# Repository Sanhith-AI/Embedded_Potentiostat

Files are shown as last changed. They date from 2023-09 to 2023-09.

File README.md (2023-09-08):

# Embedded_Potentiostat
This project mainly focuses on the development and testing of an embedded potentiostat system that can perform electrochemistry methods like Cyclic voltammetry, Square wave voltammetry, Differential pulse voltammetry, and Impedance spectroscopy.
This project includes the circuit design and PCB design of a potentiostat and power supply using Eagle Autodesk software.
The software implementation includes driver development for SPI, UART, TIMERS, DACs, and ADCs of the STM32F303ZETx microcontroller using STM32cubeIDE as well as Eclipse IDE. Along with driver development, electrochemical methods and digital signal processing methods were implemented using a microcontroller and Matlab.
Moreover, a graphic user interface (GUI) was implemented using C# and Visual Studio to automate the measurement process of the developed potentiostat.

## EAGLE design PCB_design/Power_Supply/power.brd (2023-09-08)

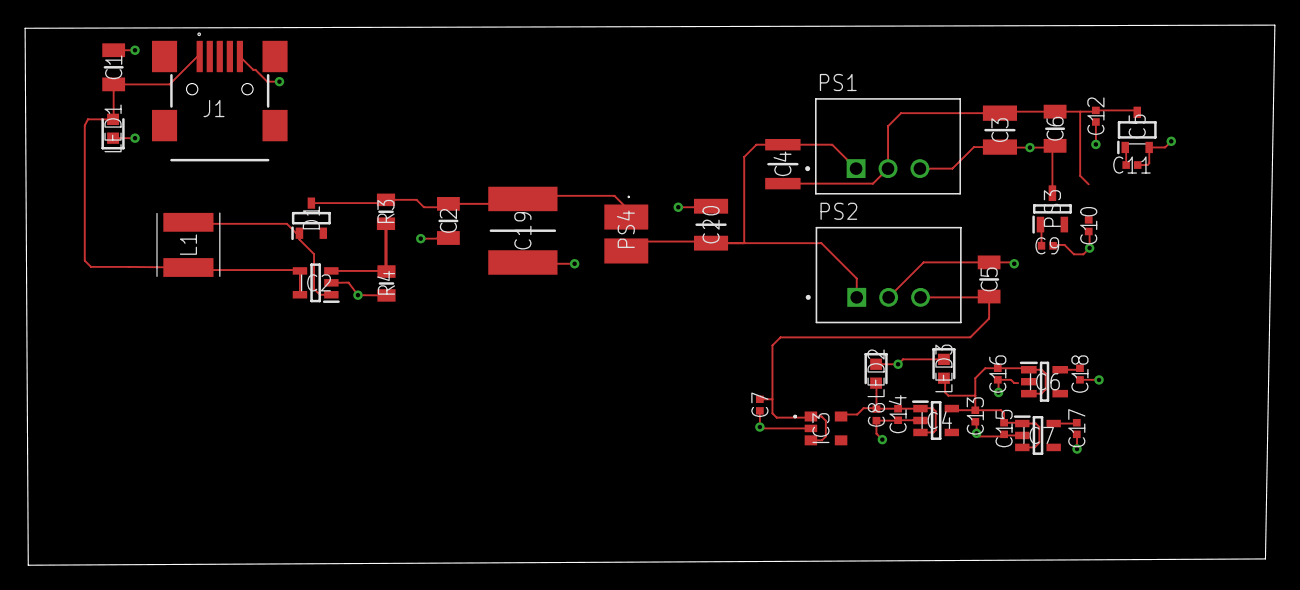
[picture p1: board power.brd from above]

Board: 2 copper layers, 99.5 x 43.0 mm, 38 parts (0 on the bottom side), 14 nets.

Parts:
C1, C2, C5, C6: LMF316AB7475KLHT; CAPC3216X180N
C3: LMF325B7106KMHP; CAPC3225X270N
C4: GRJ32ER71H106KE11L; CAPC3225X280N
C7, C8, C9, C10, C11, C12, C13, C14, C15, C16, C17, C18: GRM155R70J105KA12D; CAPC1005X55N
C19: KRM55QR72A106KH01L; CAPC6153X390N
C20: 12101C335KAT2A; CAPC3325X279N
D1: BAT54CHYFHT116; SOT95P240X115-3N
IC2: LM2703MFX-ADJ_NOPB; SOT95P280X145-5N
IC3: TCR2EF50,LM_CT; TCR2EF50LMCT
IC4: ADM7160AUJZ-2.5-R7; SOT95P280X100-5N
IC5: XC6902N251MR-G; SOT95P280X130-3N
IC6: NCV8114ASN165T1G; SOT95P275X110-5N
IC7: NCP163ASN150T1G; SOT95P280X145-5N
J1: 65100516121
L1: VLS5045EX-100M-H; VLS5045EX330M
LED1, LED2: LT_Q39G-Q1OO-25-1; LEDC1608X40N
LED3: LB_Q39E-N1OO-35-1; LEDC1608X40N
PS1, PS2: R-786.5-0.5; CONV_R-786.5-0.5
PS3: TC595002ECBTR; SOT95P275X130-3N
PS4: RLS-397; RLS397
R3, R4: TNPW080527K4BEEN; RESC2012X55N

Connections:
1.5V: C17.1, IC7.5
1.65V: C18.1, IC6.5
2.5V: C13.1, C15.1, C16.1, IC4.5, IC6.1, IC6.3, IC7.1, IC7.3, LED3.2
5V: C8.1, C14.1, IC3.5, IC4.1, IC4.3, LED2.2
6.5V: C5.1, C7.1, IC3.1, IC3.3, PS2.3
-2.5V: C11.1, IC5.1
-5V: C9.2, PS3.1
-6.5V: C3.2, C4.2, C6.1, C10.2, C12.1, IC5.3, PS1.2, PS3.2
GND: C1.2, C2.2, C3.1, C5.2, C6.2, C7.2, C8.2, C9.1, C10.1, C11.2, C12.2, C13.2, C14.2, C15.2, C16.2, C17.2, C18.2, C19.2, C20.2, IC2.2, IC3.2, IC4.2, IC5.2, IC7.2, J1.5, LED1.1, LED2.1, LED3.1, PS1.3, PS2.2, PS3.3, R4.2
IN: C2.1, C19.1, D1.3, PS4.1, R3.2
unnamed: IC2.3, R3.1, R4.1
unnamed: C4.1, C20.1, PS1.1, PS2.1, PS4.2
unnamed: D1.1, IC2.1, L1.2
VIN: C1.1, IC2.4, IC2.5, J1.1, L1.1, LED1.2

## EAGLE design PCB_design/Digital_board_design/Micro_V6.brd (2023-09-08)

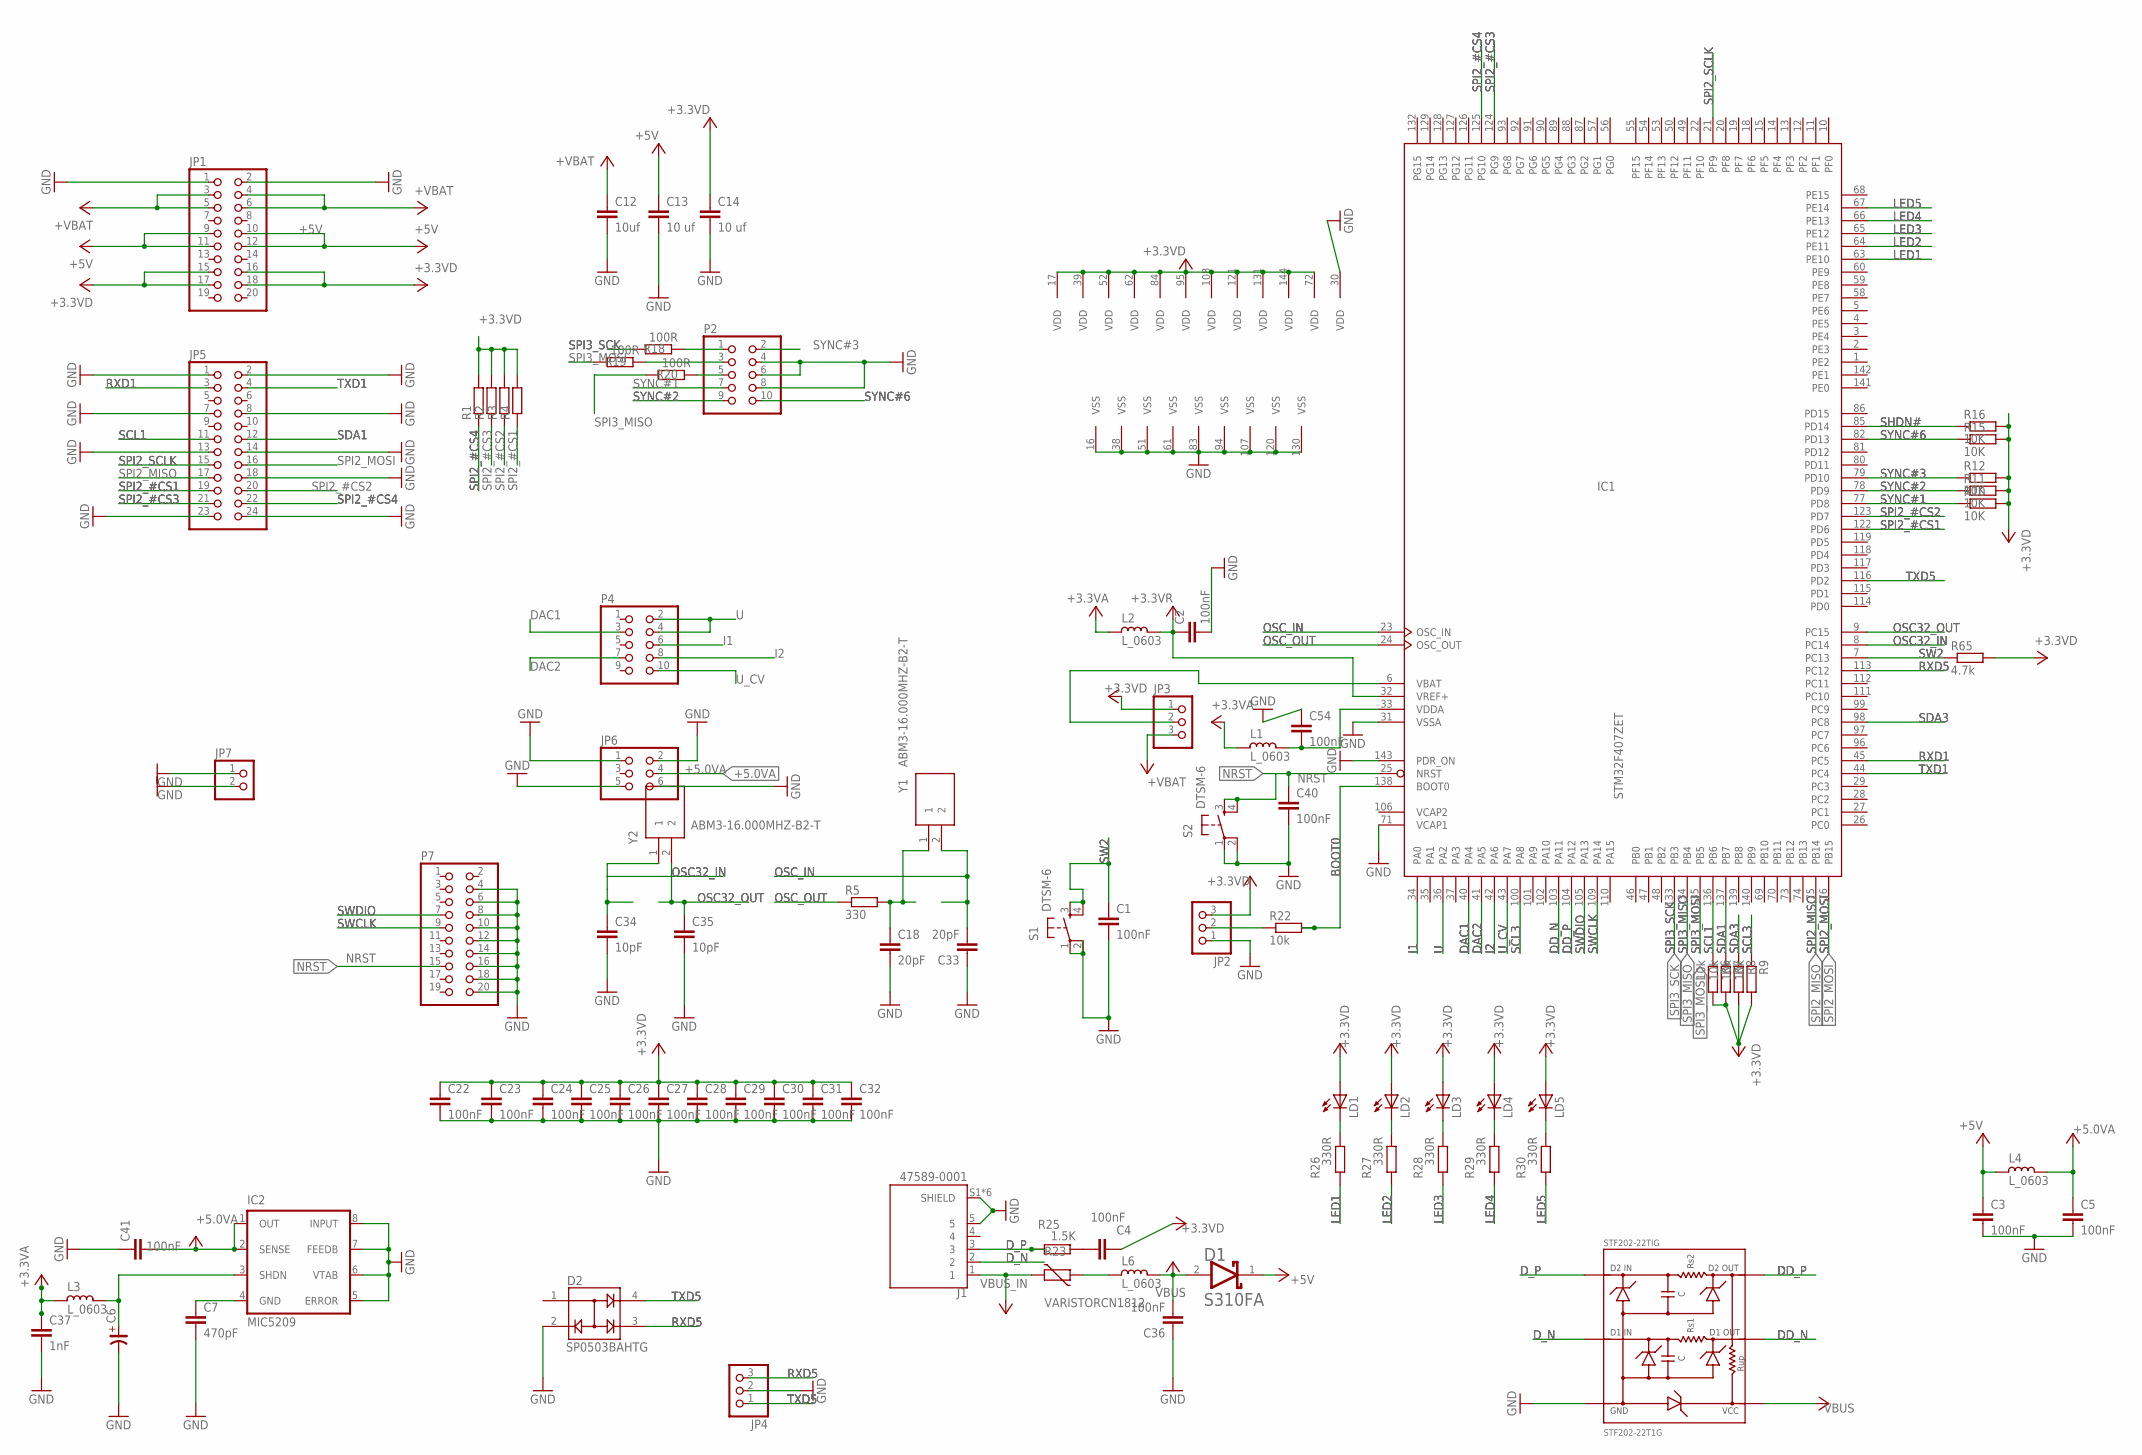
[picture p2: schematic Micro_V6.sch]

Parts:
C1, C2, C3, C4, C5, C22, C23, C24, C25, C26, C27, C28, C29, C30, C31, C32, C36, C40, C41, C54: 100nF; C0805
C6: CP_SV-A; CSV-A
C7: 470pF; C0805
C12: 10uf; C0805K
C13, C14: 10 uf; C0805K
C18, C33: 20pF; C0805
C34, C35: 10pF; C0805
C37: 1nF; C0805
D1: ON_SEMICONDUCTOR_S310FAON_SEMICONDUCTOR_S310FA_0_0; ON_SEMICONDUCTOR_S310FA_0
D2: SP0503BAHTG; SOT143
IC1: STM32F407ZET; LQFP144
IC2: MIC5209; SO-08
J1: 47589-0001; MOLEX_47589-0001
JP1: PINHD-2X10; 2X10
JP2, JP3, JP4: PINHD-1X3; 1X03
JP5: PINHD-2X12; 2X12
JP6: PINHD-2X3; 2X03
JP7: PINHD-1X2; 1X02
L1, L2, L3, L4, L6: L_0603; L0603
LD1, LD2, LD3, LD4, LD5: LEDSMT1206; 1206
P2, P4: PINHD-2X5; 2X05
P7: PINHD-2X10; 2X10
R1, R2, R3, R4: R-EU_R0603; R0603
R5: 330; R0603
R6, R7, R8, R9, R22: 10k; R0603
R10, R11, R12, R15, R16: 10K; R0603
R18, R19, R20: 100R; R0603
R23: VARISTORCN1812; CT/CN1812
R25: 1.5K; R0603
R26, R27, R28, R29, R30: 330R; R0603
R65: 4.7k; R0603
S1, S2: DTSM-6
STF202-22TIG: STF202-22T1G
Y1, Y2: ABM3-16.000MHZ-B2-T; ABM316000MHZB2T

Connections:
+3.3VA: C37.1, L1.2, L2.2, L3.2
+3.3VD: C4.1, C14.1, C22.1, C23.1, C24.1, C25.1, C26.1, C27.1, C28.1, C29.1, C30.1, C31.1, C32.1, IC1.17 (VDD), IC1.39 (VDD), IC1.52 (VDD), IC1.62 (VDD), IC1.72 (VDD), IC1.84 (VDD), IC1.95 (VDD), IC1.108 (VDD), IC1.121 (VDD), IC1.131 (VDD), IC1.144 (VDD), JP1.15, JP1.16, JP1.17, JP1.18, JP2.3, JP3.1, LD1.A, LD2.A, LD3.A, LD4.A, LD5.A, R1.2, R2.2, R3.2, R4.2, R6.2, R7.2, R8.2, R9.2, R10.2, R11.2, R12.2, R15.2, R16.2, R65.2
+3.3VR: C2.1, IC1.32 (VREF+), L2.1
+5.0VA: C5.1, C41.2, IC2.1 (OUT), IC2.2 (SENSE), JP6.4, L4.1
+5V: C3.1, C13.1, D1.1 (CATHODE), JP1.9, JP1.10, JP1.11, JP1.12, L4.2
+VBAT: C12.1, JP1.3, JP1.4, JP1.5, JP1.6, JP3.3
BOOT0: IC1.138 (BOOT0), R22.2
DAC1: IC1.40 (PA4), P4.3
DAC2: IC1.41 (PA5), P4.7
DD_N: IC1.103 (PA11), STF202-22TIG.2 (D1-IN)
DD_P: IC1.104 (PA12), STF202-22TIG.3 (D2-IN)
D_N: J1.2, STF202-22TIG.5 (D1-OUT)
D_P: J1.3, R25.1, STF202-22TIG.4 (D2-OUT)
GND: C1.2, C2.2, C3.2, C5.2, C6.-, C7.2, C12.2, C13.2, C14.2, C18.2, C22.2, C23.2, C24.2, C25.2, C26.2, C27.2, C28.2, C29.2, C30.2, C31.2, C32.2, C33.1, C34.2, C35.2, C36.1, C37.2, C40.2, C41.1, C54.1, D2.2, IC1.16 (VSS), IC1.30 (VDD), IC1.31 (VSSA), IC1.38 (VSS), IC1.51 (VSS), IC1.61 (VSS), IC1.71 (VCAP1), IC1.83 (VSS), IC1.94 (VSS), IC1.107 (VSS), IC1.120 (VSS), IC1.130 (VSS), IC1.143 (PDR_ON), IC2.5 (ERROR), IC2.6 (VTAB), IC2.7 (FEEDB), IC2.8 (INPUT), J1.5, J1.S1 (SHIELD), J1.S2 (SHIELD), J1.S3 (SHIELD), J1.S4 (SHIELD), J1.S5 (SHIELD), J1.S6 (SHIELD), JP1.1, JP1.2, JP2.1, JP4.2, JP5.1, JP5.2, JP5.7, JP5.8, JP5.13, JP5.14, JP5.18, JP5.23, JP5.24, JP6.1, JP6.2, JP6.5, JP6.6, JP7.1, JP7.2, P2.4, P2.6, P2.8, P7.4, P7.6, P7.8, P7.10, P7.12, P7.14, P7.16, P7.18, P7.20, S1.1, S1.2, S2.1, S2.2, STF202-22TIG.6 (GND)
I1: IC1.34 (PA0), P4.6
I2: IC1.42 (PA6), P4.8
LED1: IC1.63 (PE10), R26.1
LED2: IC1.64 (PE11), R27.1
LED3: IC1.65 (PE12), R28.1
LED4: IC1.66 (PE13), R29.1
LED5: IC1.67 (PE14), R30.1
unnamed: IC1.6 (VBAT), JP3.2
unnamed: C54.2, IC1.33 (VDDA), L1.1
unnamed: P2.3, R19.1
unnamed: P2.5, R20.1
unnamed: L6.2, R23.1
unnamed: P2.1, R18.1
unnamed: C18.1, R5.2, Y1.1
unnamed: JP2.2, R22.1
unnamed: C6.+, IC2.3 (SHDN), L3.1
unnamed: C7.1, IC2.4 (GND)
unnamed: C4.2, R25.2
unnamed: LD1.C, R26.2
unnamed: LD2.C, R27.2
unnamed: LD3.C, R28.2
unnamed: LD4.C, R29.2
unnamed: LD5.C, R30.2
NRST: C40.1, IC1.25 (NRST), P7.15, S2.3, S2.4
OSC32_IN: C34.1, IC1.8 (PC14), Y2.1
OSC32_OUT: C35.1, IC1.9 (PC15), Y2.2
OSC_IN: C33.2, IC1.23 (OSC_IN), Y1.2
OSC_OUT: IC1.24 (OSC_OUT), R5.1
RXD1: IC1.45 (PC5), JP5.3
RXD5: D2.3, IC1.113 (PC12), JP4.3
SCL1: IC1.136 (PB6), JP5.11, R6.1
SCL3: IC1.100 (PA8), R9.1
SDA1: IC1.137 (PB7), JP5.12, R7.1
SDA3: IC1.98 (PC8), R8.1
SHDN#: IC1.85 (PD14), R16.1
SPI2_#CS1: IC1.122 (PD6), JP5.19, R4.1
SPI2_#CS2: IC1.123 (PD7), JP5.20, R3.1
SPI2_#CS3: IC1.124 (PG9), JP5.21, R2.1
SPI2_#CS4: IC1.125 (PG10), JP5.22, R1.1
SPI2_MISO: IC1.75 (PB14), JP5.17
SPI2_MOSI: IC1.76 (PB15), JP5.16
SPI2_SCLK: IC1.21 (PF9), JP5.15
SPI3_MISO: IC1.134 (PB4), R20.2
SPI3_MOSI: IC1.135 (PB5), R19.2
SPI3_SCK: IC1.133 (PB3), R18.2
SW2: C1.1, IC1.7 (PC13), R65.1, S1.3, S1.4
SWCLK: IC1.109 (PA14), P7.9
SWDIO: IC1.105 (PA13), P7.7
SYNC#1: IC1.77 (PD8), P2.7, R10.1
SYNC#2: IC1.78 (PD9), P2.9, R11.1
SYNC#3: IC1.79 (PD10), P2.2, R12.1
SYNC#6: IC1.82 (PD13), P2.10, R15.1
TXD1: IC1.44 (PC4), JP5.4
TXD5: D2.4, IC1.116 (PD2), JP4.1
U: IC1.36 (PA2), P4.2, P4.4
U_CV: IC1.43 (PA7), P4.10
VBUS: C36.2, D1.2 (ANODE), L6.1, STF202-22TIG.1 (VCC)
VBUS_IN: J1.1, R23.2
VCAP2: IC1.106 (VCAP2)

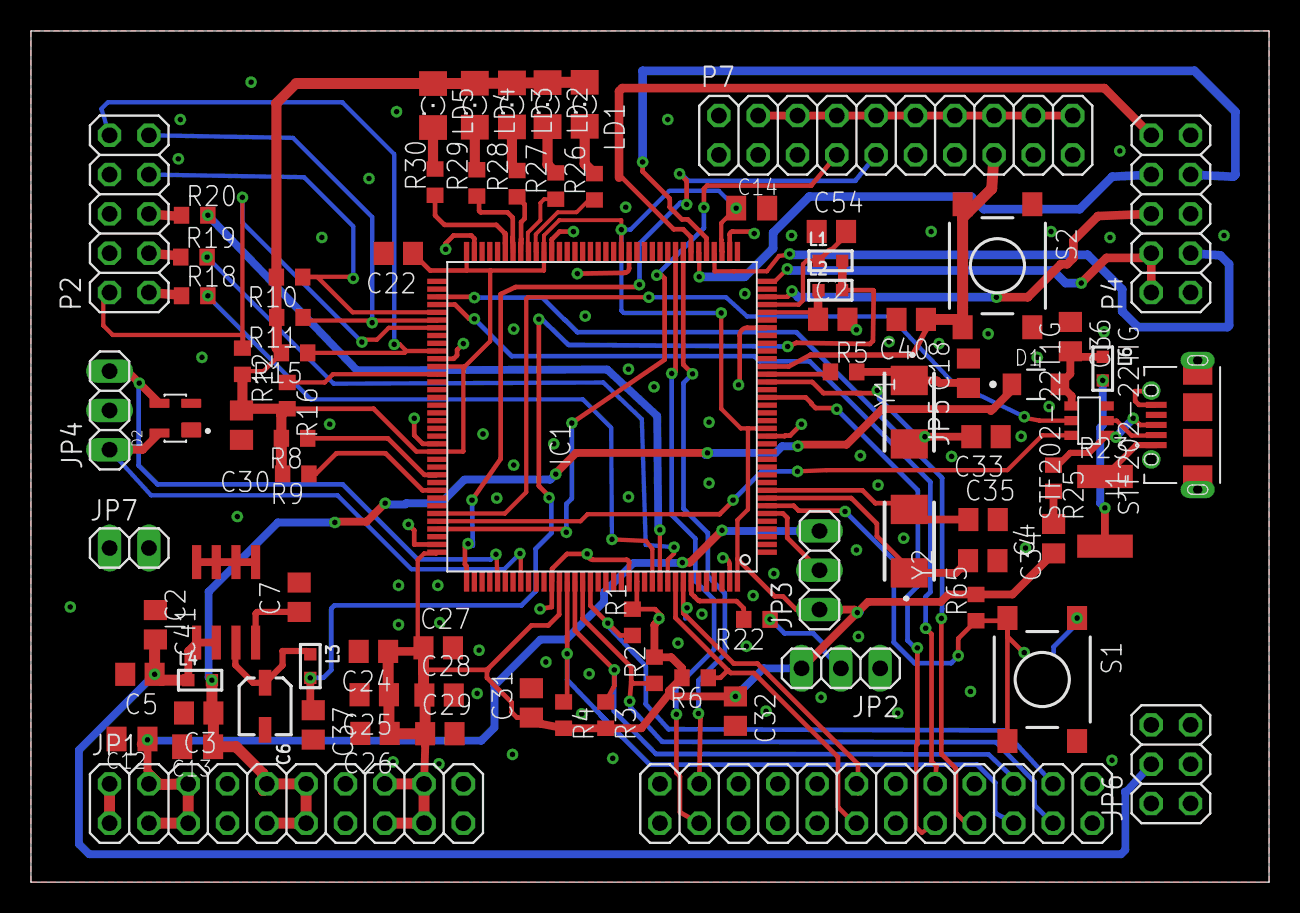
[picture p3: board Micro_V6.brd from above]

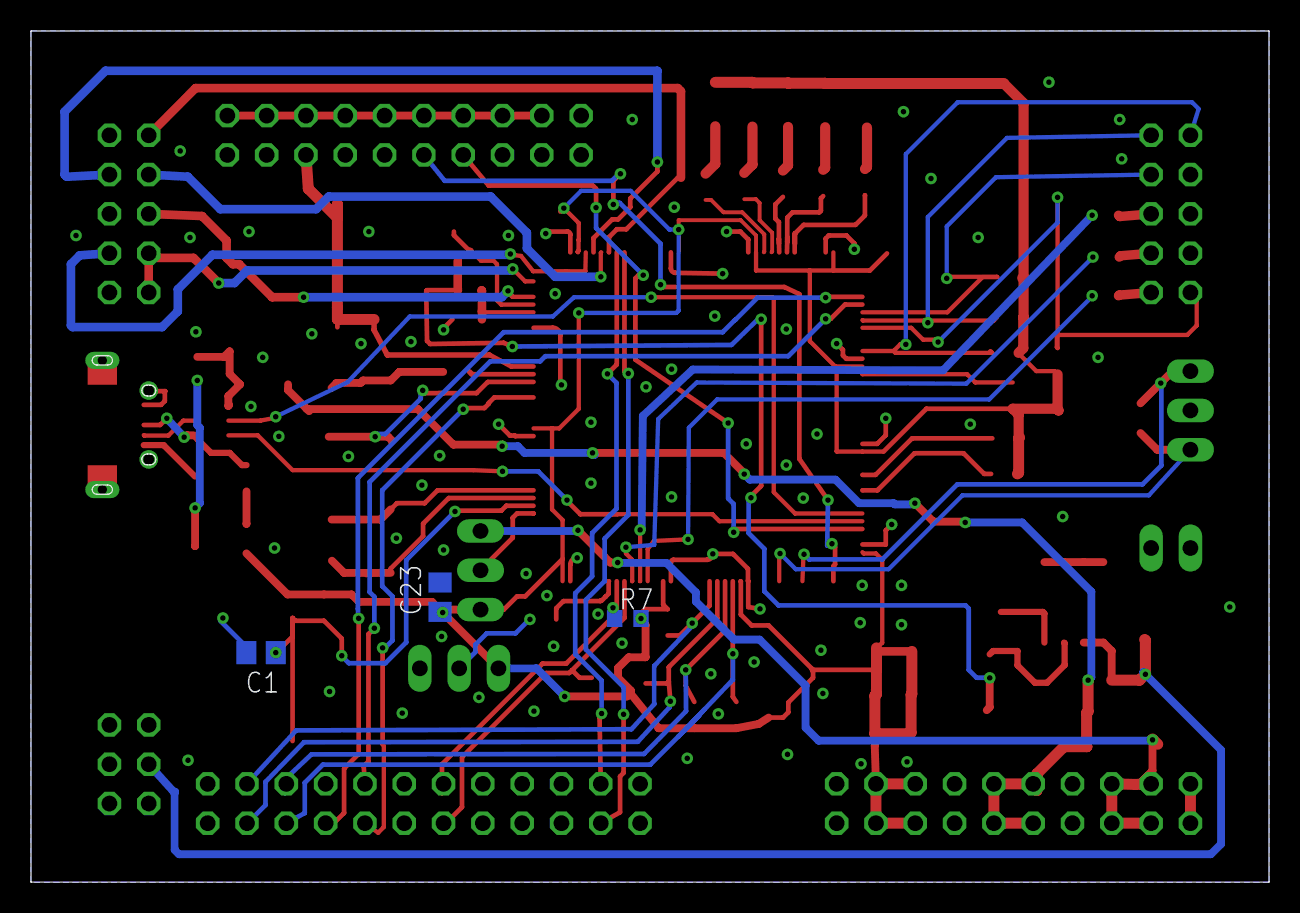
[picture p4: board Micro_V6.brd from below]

Board: 2 copper layers, 80.0 x 55.0 mm, 86 parts (3 on the bottom side), 72 nets.

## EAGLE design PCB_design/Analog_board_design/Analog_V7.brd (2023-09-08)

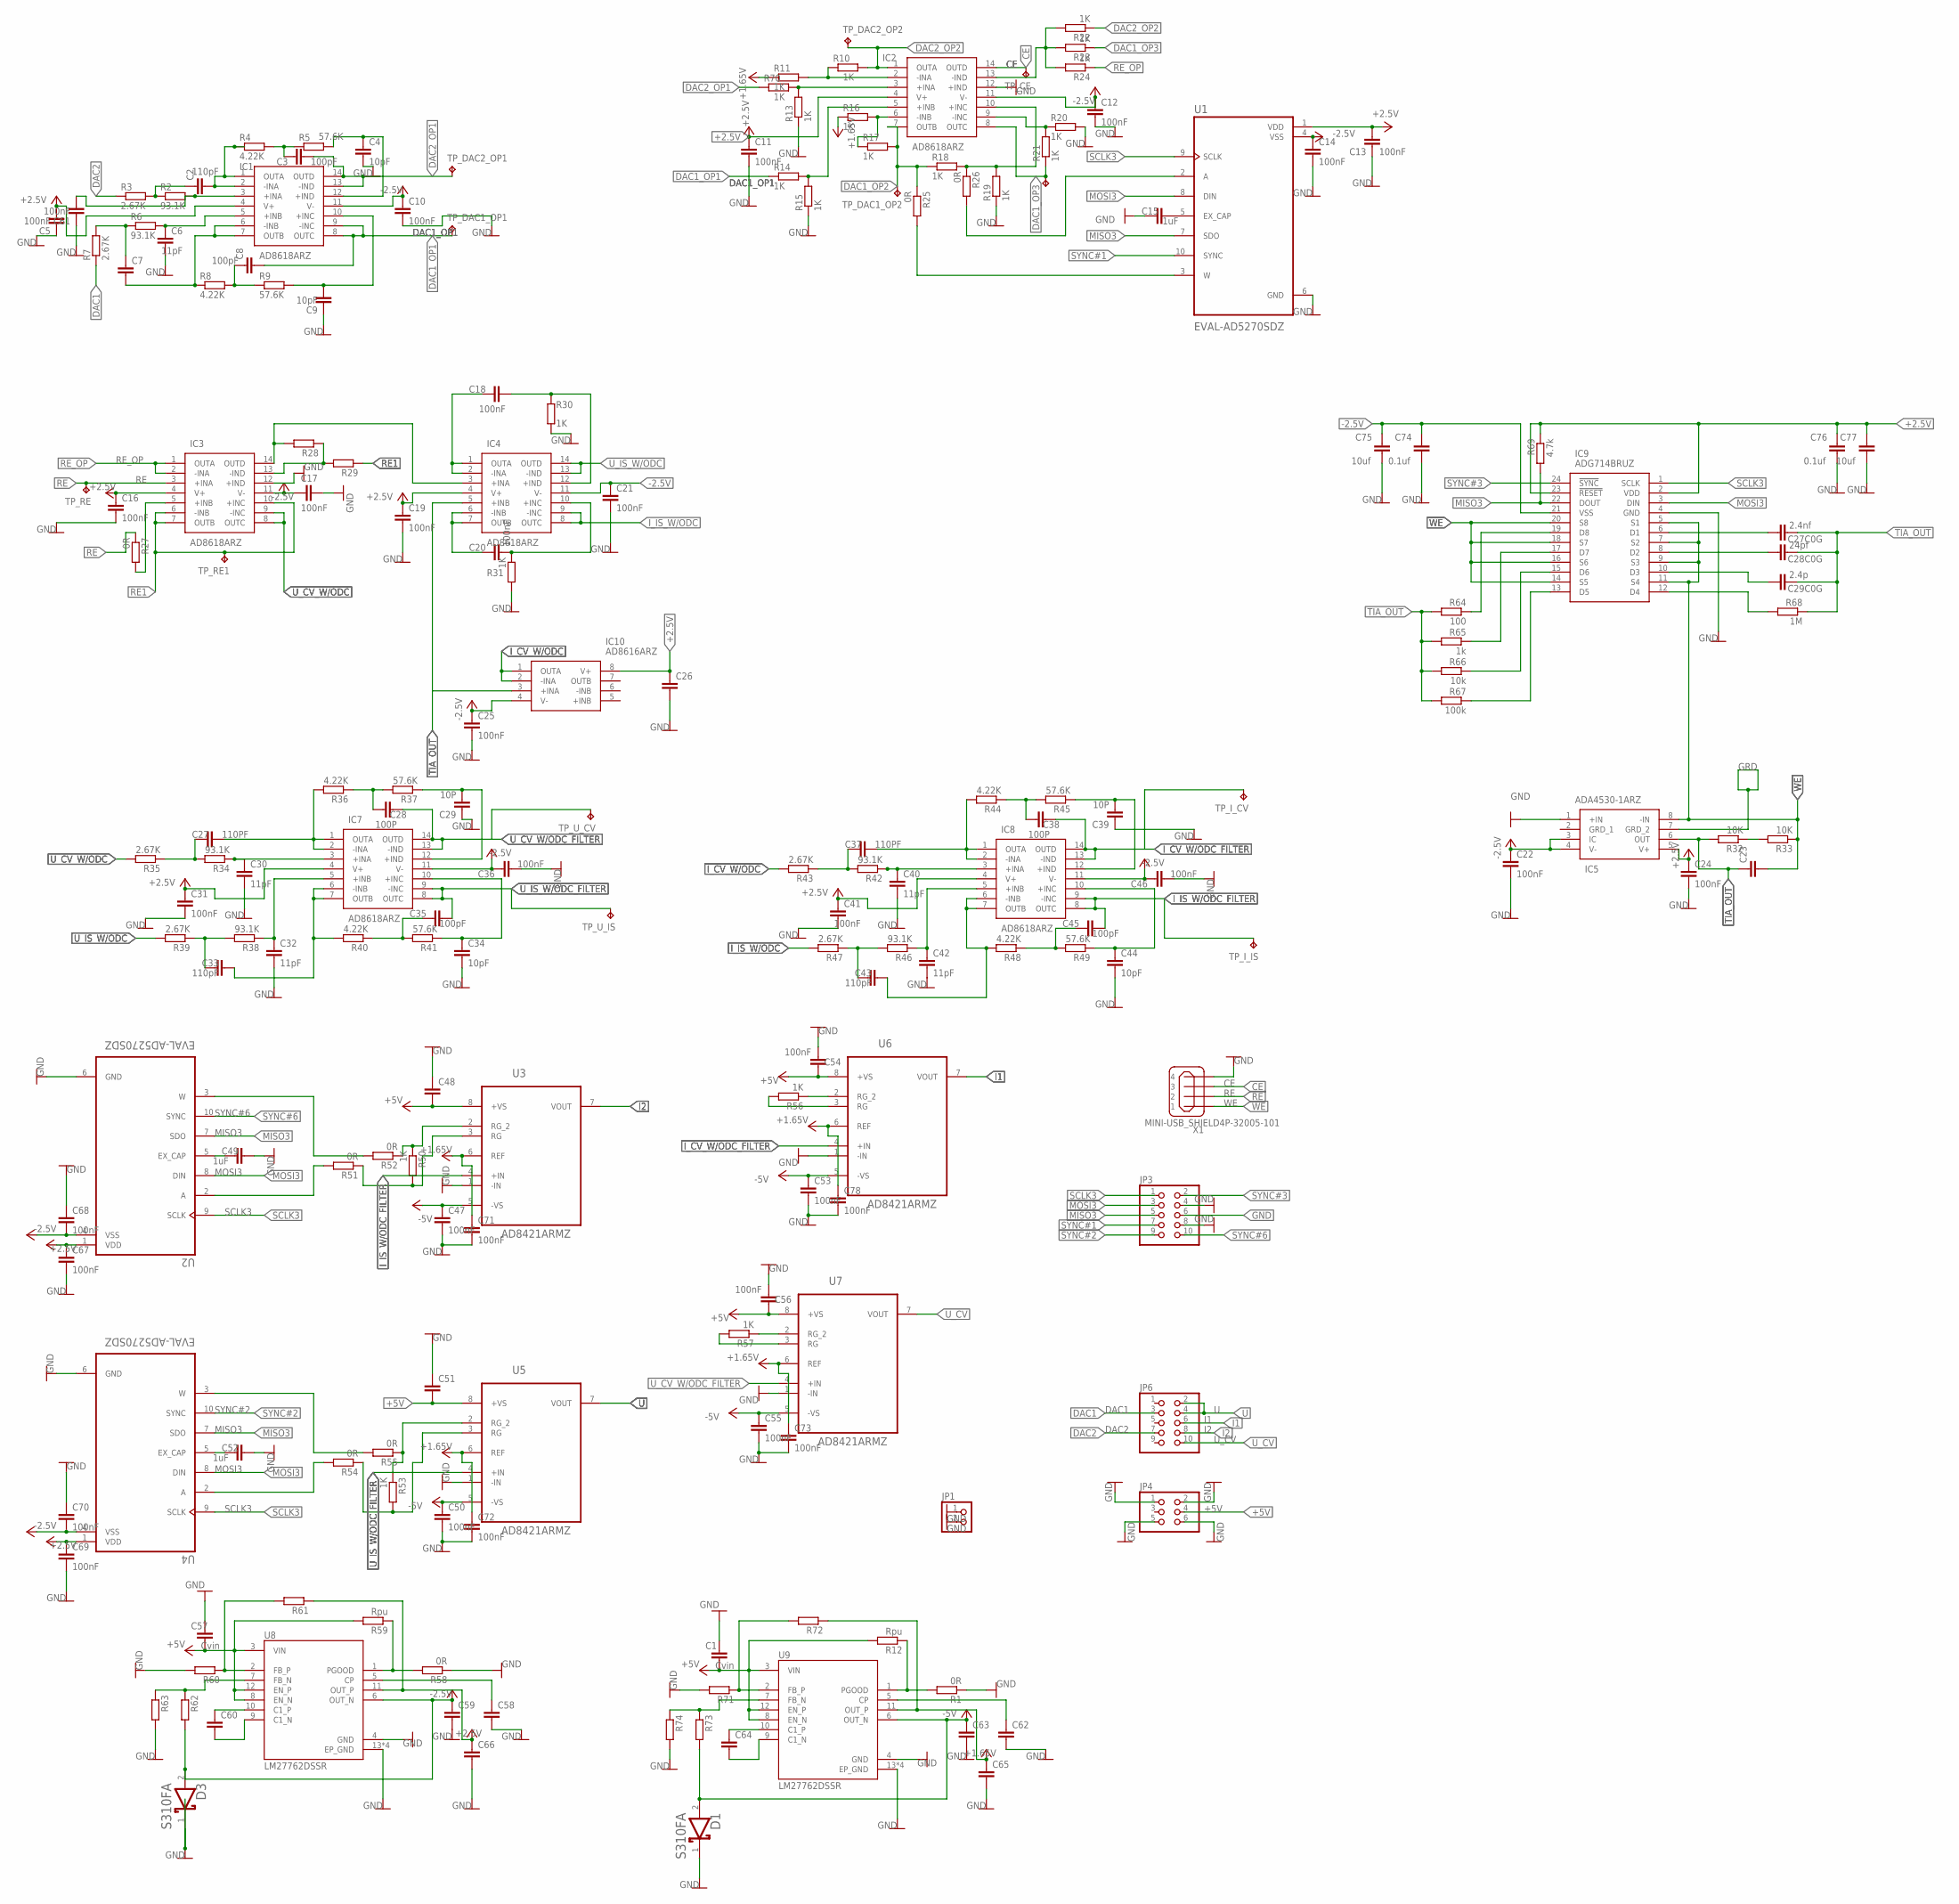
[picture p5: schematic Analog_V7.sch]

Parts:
C1, C57: Cvin; C0805
C2, C33, C43: 110pF; C0805
C3, C8, C35, C45: 100pF; C0805
C4, C9, C34, C44: 10pF; C0805
C5, C10, C11, C12, C13, C14, C16, C17, C18, C19, C20, C21, C22, C24, C25, C31, C36, C41, C46, C47, C50, C53, C54, C55, C56, C61, C67, C68, C69, C70, C71, C72, C73, C78: 100nF; C0805
C6, C30, C32, C40, C42: 11pF; C0805
C7, C23, C26, C48, C51, C58, C59, C60, C62, C63, C64, C65, C66: C-EUC0805; C0805
C15, C49, C52: 1uF; C0805
C27, C37: 110PF; C0805
C27C0G: 2.4nf; C0603
C28, C38: 100P; C0805
C28C0G: 24pf; C0603
C29, C39: 10P; C0805
C29C0G: 2.4p; C0603
C74, C76: 0.1uf; C0603
C75, C77: 10uf; C0603
D1, D3: ON_SEMICONDUCTOR_S310FAON_SEMICONDUCTOR_S310FA_0_0; ON_SEMICONDUCTOR_S310FA_0
IC1, IC2, IC3, IC4, IC7, IC8: AD8618ARZ; SOIC127P600X175-14N
IC5: ADA4530-1ARZ; SOIC127P600X175-8N
IC9: ADG714BRUZ; SOP65P640X120-24N
IC10: AD8616ARZ; SOIC127P600X175-8N
JP1: PINHD-1X2; 1X02
JP3, JP6: PINHD-2X5; 2X05
JP4: PINHD-2X3; 2X03
R1, R25, R26, R27, R51, R52, R54, R55, R58: 0R; R0603
R2, R6, R34, R38, R42, R46: 93.1K; R0603
R3, R7, R35, R39, R43, R47: 2.67K; R0603
R4, R8, R36, R40, R44, R48: 4.22K; R0603
R5, R9, R37, R41, R45, R49: 57.6K; R0603
R10, R11, R13, R14, R15, R16, R17, R18, R19, R20, R21, R22, R23, R24, R30, R31, R50, R53, R56, R57, R70: 1K; R0603
R12, R59: Rpu; R0603
R28, R29, R60, R61, R62, R63, R71, R72, R73, R74: R-EU_R0603; R0603
R32, R33: 10K; R0603
R64: 100; R0603
R65: 1k; R0603
R66: 10k; R0603
R67: 100k; R0603
R68: 1M; R0603
R69: 4.7k; R0603
TP_CE: TPB1,27; B1,27
TP_DAC1_OP1: TP_DAC1_OP1; B1,27
TP_DAC1_OP2, TP_DAC1_OP3: TPB1,27; B1,27
TP_DAC2_OP1: TP_DAC2_OP1; B1,27
TP_DAC2_OP2: TP_DAC2_OP2; B1,27
TP_I_CV: TPB1,27; B1,27
TP_I_IS: TPB1,27; B1,27
TP_RE, TP_RE1: TPB1,27; B1,27
TP_U_CV: TPB1,27; B1,27
TP_U_IS: TPB1,27; B1,27
U1, U2, U4: EVAL-AD5270SDZ; SOP50P490X110-10N
U3, U5, U6, U7: AD8421ARMZ; SOP65P490X110-8N
U8, U9: LM27762DSSR; VREG_LM27762DSSR
X1: MINI-USB_SHIELD4P-32005-101; 32005-101

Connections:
+1.65V: C65.1, C71.1, C72.1, C73.1, C78.1, R11.1, R16.1, R72.1, U3.6 (REF), U5.6 (REF), U6.6 (REF), U7.6 (REF), U9.11 (OUT_P)
+2.5V: C5.2, C11.1, C13.2, C16.1, C19.1, C24.1, C26.1, C31.1, C41.1, C66.1, C67.1, C69.1, C76.1, C77.1, IC1.4 (V+), IC2.4 (V+), IC3.4 (V+), IC4.4 (V+), IC5.5 (V+), IC7.4 (V+), IC8.4 (V+), IC9.2 (VDD), IC9.23 (!RESET), IC10.8 (V+), R61.1, R69.1, U1.1 (VDD), U2.1 (VDD), U4.1 (VDD), U8.11 (OUT_P)
+5V: C1.2, C48.2, C51.2, C54.2, C56.2, C57.2, JP4.4, R12.2, R59.2, U3.8 (+VS), U5.8 (+VS), U6.8 (+VS), U7.8 (+VS), U8.3 (VIN), U8.8 (EN_N), U8.12 (EN_P), U9.3 (VIN), U9.8 (EN_N), U9.12 (EN_P)
-2.5V: C10.1, C12.1, C14.1, C17.1, C21.1, C22.1, C25.1, C36.2, C46.2, C59.1, C68.2, C70.2, C74.1, C75.1, D3.2 (ANODE), IC1.11 (V-), IC2.11 (V-), IC3.11 (V-), IC4.11 (V-), IC5.3 (IC), IC5.4 (V-), IC7.11 (V-), IC8.11 (V-), IC9.21 (VSS), IC10.4 (V-), R62.2, U1.4 (VSS), U2.4 (VSS), U4.4 (VSS), U8.6 (OUT_N)
-5V: C47.1, C50.1, C53.1, C55.1, C63.1, D1.2 (ANODE), R73.2, U3.5 (-VS), U5.5 (-VS), U6.5 (-VS), U7.5 (-VS), U9.6 (OUT_N)
CE: IC2.14 (OUTD), TP_CE.TP, X1.3
DAC1: JP6.3, R7.1
DAC1_OP1: C8.2, IC1.8 (OUTC), IC1.9 (-INC), R14.1, TP_DAC1_OP1.TP
DAC1_OP2: IC2.7 (OUTB), R17.2, R18.1, R25.1, TP_DAC1_OP2.TP
DAC1_OP3: IC2.8 (OUTC), R21.1, R23.1, TP_DAC1_OP3.TP
DAC2: JP6.7, R3.1
DAC2_OP1: C3.2, IC1.13 (-IND), IC1.14 (OUTD), R70.1, TP_DAC2_OP1.TP
DAC2_OP2: IC2.1 (OUTA), R10.2, R22.1, TP_DAC2_OP2.TP
GND: C1.1, C4.2, C5.1, C6.2, C9.1, C10.2, C11.2, C12.2, C13.1, C14.2, C15.1, C16.2, C17.2, C19.2, C21.2, C22.2, C24.2, C25.2, C26.2, C29.1, C30.2, C31.2, C32.2, C34.2, C36.1, C39.1, C40.2, C41.2, C42.2, C44.2, C46.1, C47.2, C48.1, C49.2, C50.2, C51.1, C52.2, C53.2, C54.1, C55.2, C56.1, C57.1, C58.2, C59.2, C61.1, C62.2, C63.2, C65.2, C66.2, C67.2, C68.1, C69.2, C70.1, C71.2, C72.2, C73.2, C74.2, C75.2, C76.2, C77.2, C78.2, D1.1 (CATHODE), D3.1 (CATHODE), IC2.12 (+IND), IC3.12 (+IND), IC5.1 (+IN), IC9.4 (GND), JP1.1, JP1.2, JP3.4, JP3.6, JP3.8, JP4.1, JP4.2, JP4.5, JP4.6, R1.1, R13.1, R15.1, R19.1, R20.2, R30.2, R31.2, R58.1, R60.2, R63.2, R71.2, R74.2, U1.6 (GND), U2.6 (GND), U3.1 (-IN), U5.1 (-IN), U6.1 (-IN), U7.1 (-IN), U8.4 (GND), U8.13 (EP_GND), U8.13.1 (EP_GND), U8.13.2 (EP_GND), U8.13.3 (EP_GND), U9.4 (GND), U9.13 (EP_GND), U9.13.1 (EP_GND), U9.13.2 (EP_GND), U9.13.3 (EP_GND), X1.4
GND1: U4.6 (GND)
GRD: IC5.7 (GRD_2)
I1: JP6.6, U6.7 (VOUT)
I2: JP6.8, U3.7 (VOUT)
I_CV_W/ODC: IC10.1 (OUTA), IC10.2 (-INA), R43.2
I_CV_W/ODC_FILTER: C38.2, IC8.13 (-IND), IC8.14 (OUTD), TP_I_CV.TP, U6.4 (+IN)
I_IS_W/ODC: IC4.8 (OUTC), IC4.9 (-INC), R47.2
I_IS_W/ODC_FILTER: C45.2, IC8.8 (OUTC), IC8.9 (-INC), TP_I_IS.TP, U3.4 (+IN)
MISO3: IC9.22 (DOUT), JP3.5, R69.2, U1.7 (SDO), U2.7 (SDO), U4.7 (SDO)
MOSI3: IC9.3 (DIN), JP3.3, U1.8 (DIN), U2.8 (DIN), U4.8 (DIN)
unnamed: C2.2, IC1.1 (OUTA), IC1.2 (-INA), R4.1
unnamed: C7.2, IC1.6 (-INB), IC1.7 (OUTB), R8.1
unnamed: IC2.9 (-INC), R20.1, R21.2
unnamed: C61.2, IC1.3 (+INA), R2.2
unnamed: C3.1, R4.2, R5.1
unnamed: IC2.3 (+INA), R13.2, R70.2
unnamed: C6.1, IC1.5 (+INB), R6.2
unnamed: C7.1, R6.1, R7.2
unnamed: IC2.2 (-INA), R10.1, R11.2
unnamed: C8.1, R8.2, R9.1
unnamed: C9.2, IC1.10 (+INC), R9.2
unnamed: IC2.5 (+INB), R14.2, R15.2
unnamed: IC2.6 (-INB), R16.2, R17.1
unnamed: C4.1, IC1.12 (+IND), R5.2
unnamed: IC2.13 (-IND), R22.2, R23.2, R24.2
unnamed: R25.2, U1.3 (W)
unnamed: R26.2, U1.2 (A)
unnamed: C15.2, U1.5 (EX_CAP)
unnamed: IC3.5 (+INB), R27.2
unnamed: IC3.14 (OUTD), IC4.3 (+INA), R28.2
unnamed: IC3.13 (-IND), R28.1, R29.2
unnamed: C18.1, IC4.1 (OUTA), IC4.2 (-INA)
unnamed: C20.1, IC4.6 (-INB), IC4.7 (OUTB)
unnamed: C27.2, IC7.1 (OUTA), IC7.2 (-INA), R36.2
unnamed: IC9.19 (D8), R64.1
unnamed: R32.1, R33.2
unnamed: C30.1, IC7.3 (+INA), R34.1
unnamed: C27.1, R34.2, R35.1
unnamed: C28.1, R36.1, R37.2
unnamed: C33.2, IC7.6 (-INB), IC7.7 (OUTB), R40.2
unnamed: C33.1, R38.2, R39.1
unnamed: C37.2, IC8.1 (OUTA), IC8.2 (-INA), R44.2
unnamed: C32.1, IC7.5 (+INB), R38.1
unnamed: C35.1, R40.1, R41.2
unnamed: C34.1, IC7.10 (+INC), R41.1
unnamed: C40.1, IC8.3 (+INA), R42.1
unnamed: C37.1, R42.2, R43.1
unnamed: C38.1, R44.1, R45.2
unnamed: C43.2, IC8.6 (-INB), IC8.7 (OUTB), R48.2
unnamed: C43.1, R46.2, R47.1
unnamed: C42.1, IC8.5 (+INB), R46.1
unnamed: C45.1, R48.1, R49.2
unnamed: C44.1, IC8.10 (+INC), R49.1
unnamed: R50.1, R52.1, U3.2 (RG_2)
unnamed: R50.2, R51.1, U3.3 (RG)
unnamed: R52.2, U2.3 (W)
unnamed: R51.2, U2.2 (A)
unnamed: R56.1, U6.2 (RG_2)
unnamed: C49.1, U2.5 (EX_CAP)
unnamed: R53.1, R55.1, U5.2 (RG_2)
unnamed: C64.1, U9.10 (C1_P)
unnamed: R55.2, U4.3 (W)
unnamed: R54.2, U4.2 (A)
unnamed: R56.2, U6.3 (RG)
unnamed: C52.1, U4.5 (EX_CAP)
unnamed: R57.1, U7.2 (RG_2)
unnamed: C18.2, IC4.12 (+IND), R30.1
unnamed: R57.2, U7.3 (RG)
unnamed: IC9.17 (D7), R65.1
unnamed: IC9.15 (D6), R66.1
unnamed: IC9.13 (D5), R67.1
unnamed: C27C0G.2, IC9.6 (D1)
unnamed: C60.1, U8.10 (C1_P)
unnamed: C60.2, U8.9 (C1_N)
unnamed: C28C0G.2, IC9.8 (D2)
unnamed: C29C0G.2, IC9.10 (D3)
unnamed: IC9.12 (D4), R68.2
unnamed: C20.2, IC4.10 (+INC), R31.1
unnamed: C64.2, U9.9 (C1_N)
unnamed: R71.1, R72.2, U9.2 (FB_P)
unnamed: IC2.10 (+INC), R18.2, R19.2, R26.1
unnamed: R1.2, R12.1, U9.1 (PGOOD)
unnamed: C2.1, R2.1, R3.2
unnamed: C29.2, IC7.12 (+IND), R37.1
unnamed: C39.2, IC8.12 (+IND), R45.1
unnamed: R53.2, R54.1, U5.3 (RG)
unnamed: R60.1, R61.2, U8.2 (FB_P)
unnamed: R58.2, R59.1, U8.1 (PGOOD)
unnamed: C58.1, U8.5 (CP)
unnamed: R62.1, R63.1, U8.7 (FB_N)
unnamed: C62.1, U9.5 (CP)
unnamed: R73.1, R74.1, U9.7 (FB_N)
RE: IC3.3 (+INA), R27.1, TP_RE.TP, X1.2
RE1: IC3.6 (-INB), IC3.7 (OUTB), IC3.10 (+INC), R29.1, TP_RE1.TP
RE_OP: IC3.1 (OUTA), IC3.2 (-INA), R24.1
SCLK3: IC9.1 (SCLK), JP3.1, U1.9 (SCLK), U2.9 (SCLK), U4.9 (SCLK)
SYNC#1: JP3.7, U1.10 (SYNC)
SYNC#2: JP3.9, U4.10 (SYNC)
SYNC#3: IC9.24 (!SYNC), JP3.2
SYNC#6: JP3.10, U2.10 (SYNC)
TIA_OUT: C23.1, C27C0G.1, C28C0G.1, C29C0G.1, IC4.5 (+INB), IC5.6 (OUT), IC10.3 (+INA), R32.2, R64.2, R65.2, R66.2, R67.2, R68.1
U: JP6.2, JP6.4, U5.7 (VOUT)
U_CV: JP6.10, U7.7 (VOUT)
U_CV_W/ODC: IC3.8 (OUTC), IC3.9 (-INC), R35.2
U_CV_W/ODC_FILTER: C28.2, IC7.13 (-IND), IC7.14 (OUTD), TP_U_CV.TP, U7.4 (+IN)
U_IS_W/ODC: IC4.13 (-IND), IC4.14 (OUTD), R39.2
U_IS_W/ODC_FILTER: C35.2, IC7.8 (OUTC), IC7.9 (-INC), TP_U_IS.TP, U5.4 (+IN)
WE: C23.2, IC5.8 (-IN), IC9.5 (S1), IC9.7 (S2), IC9.9 (S3), IC9.11 (S4), IC9.14 (S5), IC9.16 (S6), IC9.18 (S7), IC9.20 (S8), R33.1, X1.1

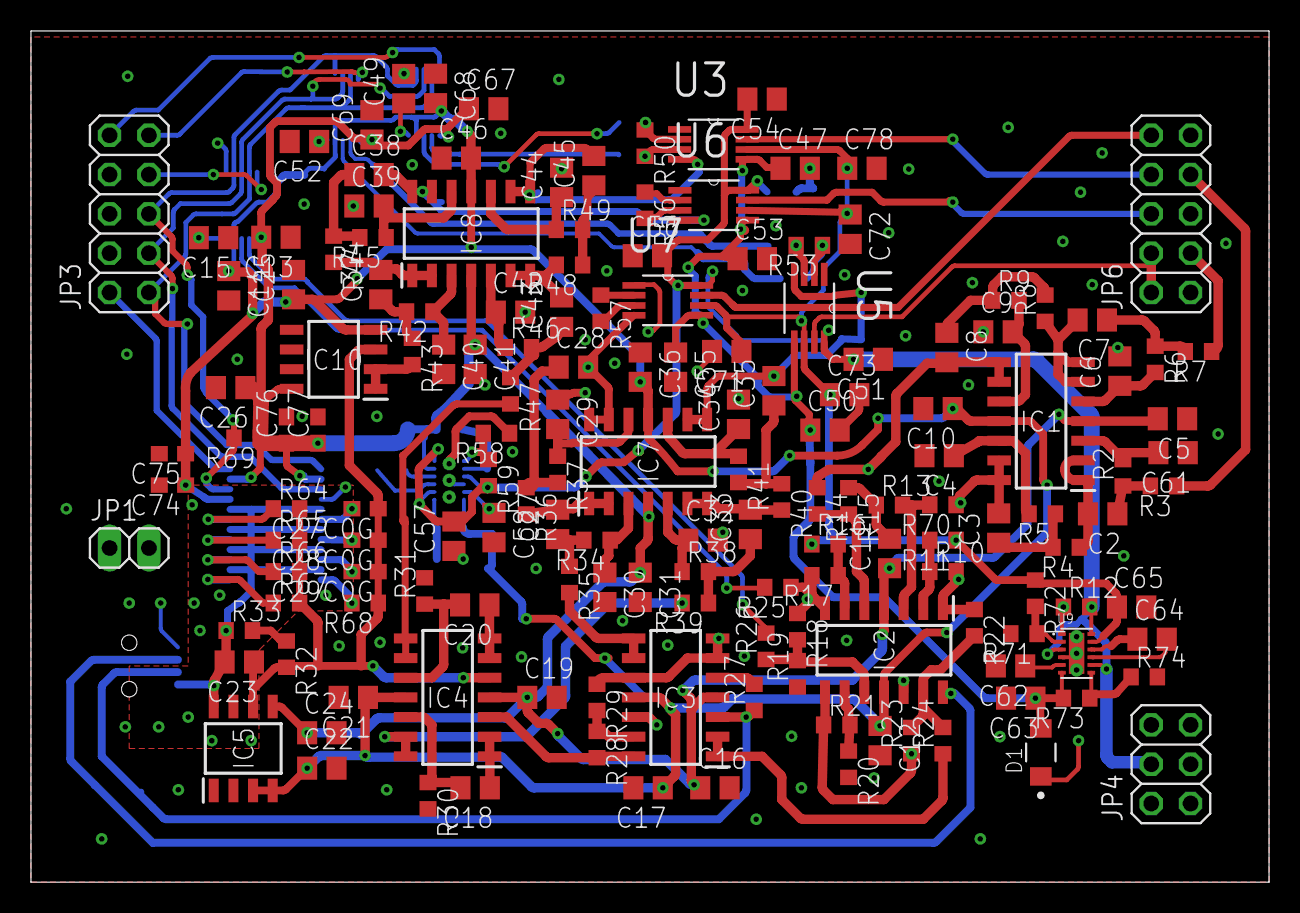
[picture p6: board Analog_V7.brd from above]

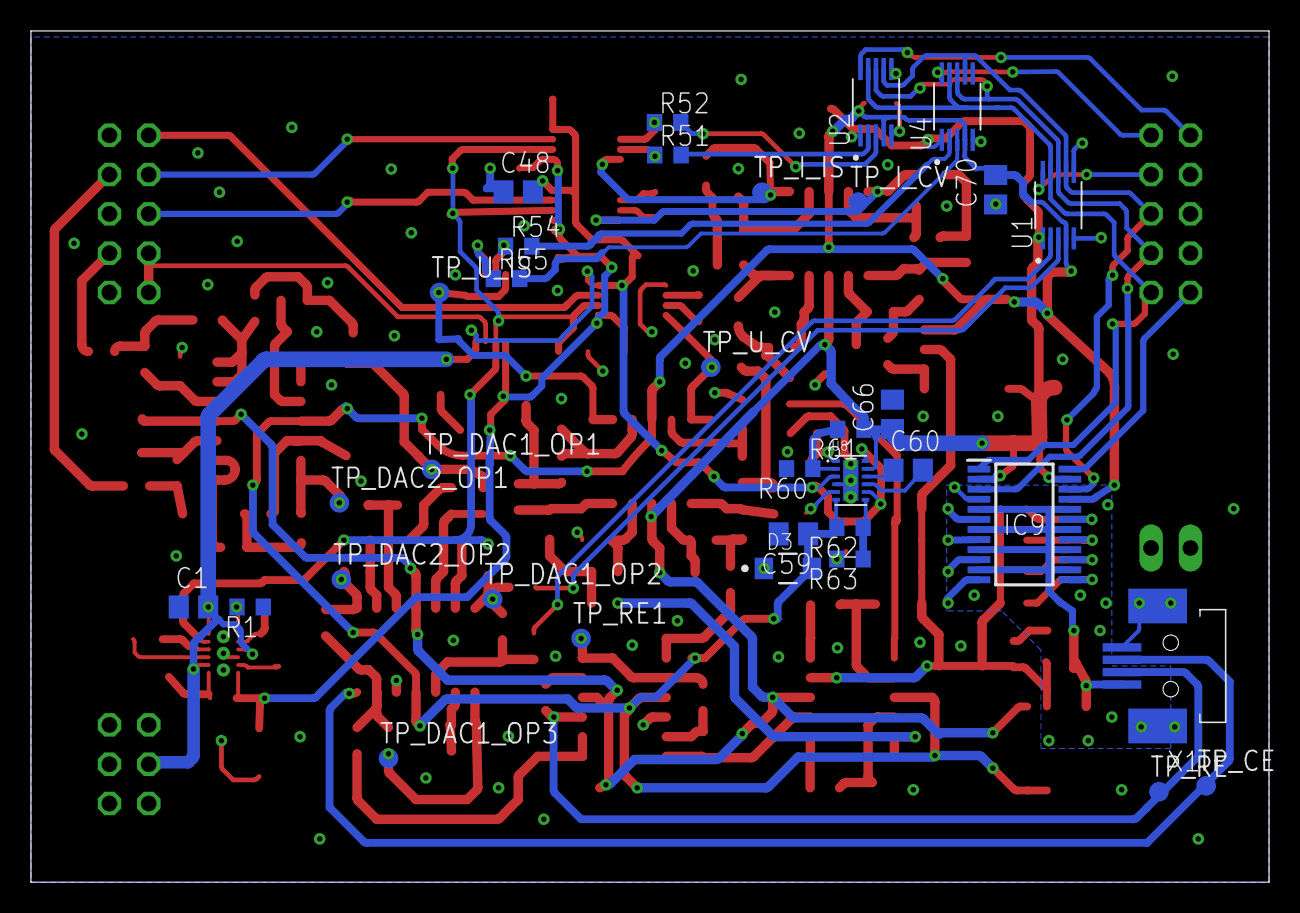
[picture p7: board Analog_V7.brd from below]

Board: 2 copper layers, 80.0 x 55.0 mm, 192 parts (34 on the bottom side), 120 nets.

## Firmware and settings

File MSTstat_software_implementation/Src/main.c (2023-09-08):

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
/* Includes ------------------------------------------------------------------*/
#include "main.h"

/* USER CODE BEGIN Includes */
#include "User_Function.h"
#include "Peripheral_Initial.h"
#include "string.h"
#include "stdio.h"
#include<math.h>
#include<stdlib.h>
/* USER CODE END Includes */

/* USER CODE BEGIN PTD */
uint8_t receivedData[40];
uint8_t unit_temp;

uint* temp0;
uint* temp1;
uint* temp2;
uint* temp3;
uint* temp4;
uint* temp5;
uint* temp6;
uint* temp7;
uint* temp8;
uint* temp9;

int8_t *UARTTemp;
char transmit_buffer[40];
uint8_t buff_length;

int method = 0;
char methodName [20];
 char unit[4];

//Variables for Impedance spectroscopy
char frequency_type[6];
char min_frequency_unit[4];
char max_frequency_unit[4];
char error[50];
int rand_count=1;
uint16_t Frequency_List[IS_MaxNoOfSineFreq];
float Frequency_List1[IS_MaxNoOfSineFreq];
uint8_t IS_default_switch_value=0x04;

/* USER CODE END PTD */

SPI_HandleTypeDef hspi3;

UART_HandleTypeDef huart4;
UART_HandleTypeDef huart5;

/* USER CODE BEGIN PV */

//char sendingData[30];
/* USER CODE END PV */

void SystemClock_Config(void);
static void MX_GPIO_Init(void);
static void MX_UART4_Init(void);
static void MX_UART5_Init(void);
static void MX_SPI3_Init(void);
/* USER CODE BEGIN 0 */
void Nucleo_LED(void);
void Nucleo_LED()
{
	RCC->AHBENR |= 0x040000;
	GPIOB->MODER |=0x4000;
	LED_On_GPIO_SetLow(GPIOB,GPIO_PIN_7);
//	LED_Off_GPIO_SetHigh(GPIOB,GPIO_PIN_7);
}


/* USER CODE END 0 */

/**
  * @brief  The application entry point.
  * @retval int
  */
int main(void)
{
  /* MCU Configuration--------------------------------------------------------*/

  /* Reset of all peripherals, Initializes the Flash interface and the Systick. */
  HAL_Init();

  /* Configure the system clock */
  SystemClock_Config();

  /* Initialize all configured peripherals */
  MX_GPIO_Init();
  MX_UART4_Init();
  MX_UART5_Init();
  MX_SPI3_Init();
  /* USER CODE BEGIN 2 */
  General_GPIO_Init();

  /* USER CODE END 2 */

  /* Infinite loop */
  /* USER CODE BEGIN WHILE */
  Nucleo_LED();


  while(1)
  {

	  	 HAL_UART_Receive(&huart5, receivedData, 40,5000);

	  	  	  	temp9=(uint*)(receivedData[36]|(receivedData[37]<<8)|(receivedData[38]<<16)|(receivedData[39]<<24));
	  	    	temp8=(uint*)(receivedData[32]|(receivedData[33]<<8)|(receivedData[34]<<16)|(receivedData[35]<<24));
	  	    	temp7=(uint*)(receivedData[28]|(receivedData[29]<<8)|(receivedData[30]<<16)|(receivedData[31]<<24));
	  	    	temp6=(uint*)(receivedData[24]|(receivedData[25]<<8)|(receivedData[26]<<16)|(receivedData[27]<<24));
	  	    	temp5=(uint*)(receivedData[20]|(receivedData[21]<<8)|(receivedData[22]<<16)|(receivedData[23]<<24));
	  	    	temp4=(uint*)(receivedData[16]|(receivedData[17]<<8)|(receivedData[18]<<16)|(receivedData[19]<<24));
	  	    	temp3=(uint*)(receivedData[12]|(receivedData[13]<<8)|(receivedData[14]<<16)|(receivedData[15]<<24));
	  	    	temp2=(uint*)(receivedData[8]|(receivedData[9]<<8)|(receivedData[10]<<16)|(receivedData[11]<<24));
	  	    	temp1=(uint*)(receivedData[4]|(receivedData[5]<<8)|(receivedData[6]<<16)|(receivedData[7]<<24));
	  	    	temp0=(uint*)(receivedData[0]|(receivedData[1]<<8)|(receivedData[2]<<16)|(receivedData[3]<<24));

	  	    	int method_temp = *(int*)&temp0;

	  	    	if(method_temp==1)
	  	    	{
	  	    		method= *(int*)&temp0;
	  	    		receivedData[0] = 0;
	  	    		receivedData[1] = 0;
	  	    		receivedData[2] = 0;
	  	    		receivedData[3] = 0;
	  	    		sprintf(methodName,"Cyclic");
	  	    		CVT.estart=*(float*)&temp1;
	  	    		CVT.estop=*(float*)&temp2;
	  	    		CVT.current=*(int*)&temp3;
	  	    		int unit_temp=*(int*)&temp4;
	  	    		if(unit_temp==1)
	  	    		{
	  	    			sprintf(unit,"pA");
	  	    		}
	  	    		else if(unit_temp ==2)
	  	    		{
	  	    			sprintf(unit,"nA");
	  	    		}
	  	    		else if(unit_temp==3)
	  	    		{
	  	    			sprintf(unit,"µA");
	  	    		}
	  	    		else
	  	    		{
	  	    			sprintf(unit,"mA");
	  	    		}
	  	    		CVT.estep=*(float*)&temp5;

	  	    		CVT.scanrate=*(float*)&temp6;
	  	    		CVT.noofscans=*(int*)&temp7;

	  	    	}
	  	    	else if(method_temp==2)
	  	    	{
	  	    		method= *(int*)&temp0;
	  	    		receivedData[0] = 0;
	  	    		receivedData[1] = 0;
	  	    		receivedData[2] = 0;
	  	    		receivedData[3] = 0;
	  	    		sprintf(methodName,"Square wave");
	  	    		CVT.estart=*(float*)&temp1;
	  	    		CVT.estop=*(float*)&temp2;
	  	    		CVT.current=*(int*)&temp3;
	  	    		int unit_temp=*(int*)&temp4;
	  	    		if(unit_temp==1)
	  	    		{
	  	    			sprintf(unit,"pA");
	  	    		}
	  	    		else if(unit_temp ==2)
	  	    		{
	  	    			sprintf(unit,"nA");
	  	    		}
	  	    		else if(unit_temp==3)
	  	    		{
	  	    			sprintf(unit,"µA");
	  	    		}
	  	    		else
	  	    		{
	  	    			sprintf(unit,"mA");
	  	    		}

	  	    		CVT.estep=*(float*)&temp5;
	  	    		SWVT.amplitude=*(float*)&temp6;
	  	    		SWVT.frequency=*(float*)&temp7;

	  	    	}
	  	    	else if(method_temp==4)
	  	    	{
	  	    		method= *(int*)&temp0;
	  	    		receivedData[0] = 0;
	  	    		receivedData[1] = 0;
	  	    		receivedData[2] = 0;
	  	    		receivedData[3] = 0;
	  	    		sprintf(methodName,"Differential pulse");
	  	    		CVT.estart=*(float*)&temp1;
	  	    		CVT.estop=*(float*)&temp2;
	  	    		CVT.current=*(int*)&temp3;
	  	    		int unit_temp=*(int*)&temp4;
	  	    		if(unit_temp==1)
	  	    		{
	  	    			sprintf(unit,"pA");
	  	    		}
	  	    		else if(unit_temp ==2)
	  	    		{
	  	    			sprintf(unit,"nA");
	  	    		}
	  	    		else if(unit_temp==3)
	  	    		{
	  	    			sprintf(unit,"µA");
	  	    		}
	  	    		else
	  	    		{
	  	    			sprintf(unit,"mA");
	  	    		}

	  	    		CVT.estep=*(float*)&temp5;
	  	    		DPVT.amplitude=*(float*)&temp6;
	  	    		CVT.scanrate=*(float*)&temp7;
	  	    		DPVT.Tpulse=*(float*)&temp8;

	  	    	}
	  	    	else if(method_temp==3)
	  	    	{
	  	    		method= *(int*)&temp0;
	  	    		receivedData[0] = 0;
	  	    		receivedData[1] = 0;
	  	    		receivedData[2] = 0;
	  	    		receivedData[3] = 0;
	  	    		sprintf(methodName,"Impedance");
	  	    		IST.edc=*(float*)&temp1;
	  	    		IST.eac=*(float*)&temp2;
	  	    		IST.current=*(int*)&temp3;
	  	    		int unit_temp=*(int*)&temp4;
	  	    		if(unit_temp==1)
	  	    		{
	  	    			sprintf(unit,"pA");
	  	    		}
	  	    		else if(unit_temp ==2)
	  	    		{
	  	    			sprintf(unit,"nA");
	  	    		}
	  	    		else if(unit_temp==3)
	  	    		{
	  	    			sprintf(unit,"µA");
	  	    		}
	  	    		else
	  	    		{
	  	    			sprintf(unit,"mA");
	  	    		}
	  	    		int freqtypeno=*(int*)&temp5;
	  	    		if(freqtypeno==1)
	  	    		{
	  	    			sprintf(frequency_type,"Fixed");
	  	    		}
	  	    		else if (freqtypeno==2)
	  	    		{
	  	    			sprintf(frequency_type,"Scan");
	  	    		}
	  	    		else
	  	    		{
	  	    			sprintf(frequency_type,"NA");
	  	    		}
	  	    		IST.frequency=*(float*)&temp6;
	  	    		IST.min_frequency=*(float*)&temp7;
	  	    		int temp_freqtype;
	  	    		temp_freqtype = *(int*)&temp8;

	  	    		if(temp_freqtype==1)
	  	    		{
	  	    			sprintf(min_frequency_unit,"Hz");
	  	    		}
	  	    		else if (temp_freqtype==2)
	  	    		{
	  	    			sprintf(min_frequency_unit,"kHz");
	  	    		}
	  	    		else
	  	    		{
	  	    			sprintf(min_frequency_unit,"NA");
	  	    		}
	  	    		IST.max_frequency=*(float*)&temp9;
	  	    		if(IST.max_frequency)
	  	    		{
	  	    			sprintf(max_frequency_unit,"kHz");
	  	    		}
	  	    		else
	  	    		{
	  	    			sprintf(max_frequency_unit,"NA");
	  	    		}


	  	    	}
	  	    	else
	  	    	{

	  	    		if(method == 0)
	  	    		{
	  	    			sprintf(error,"Waiting for receivedData");
	  	    		}
	  	    		else
	  	    		{
	  	    			sprintf(error,"Error while receiving receivedData");
	  	    		}
	  	    	}
if(rand_count==1)
{
	if((method==1) | (method==2) | (method==4))
	{


		  CV_Flag_Var_Init();

		  uint8_t switch_volta=0x14;

		  HAL_GPIO_WritePin(GPIOD, GPIO_PIN_10, GPIO_PIN_RESET);

		  HAL_SPI_Transmit(&hspi3,&switch_volta,1,100);

		  HAL_GPIO_WritePin(GPIOD, GPIO_PIN_10, GPIO_PIN_SET);

	}

	else if(method==3)
	{

		  HAL_GPIO_WritePin(GPIOD, GPIO_PIN_10, GPIO_PIN_RESET);

		  HAL_SPI_Transmit(&hspi3,&IS_default_switch_value,1,100);

		  HAL_GPIO_WritePin(GPIOD, GPIO_PIN_10, GPIO_PIN_SET);





		if(IST.frequency!=0)
		{
			Frequency_List[0] = (uint16_t)IST.frequency;
			Frequency_List[1] =0;
			Frequency_List1[0] = IST.frequency;
			Frequency_List1[1] =0;
		}

		else if(IST.min_frequency==1)
		{
			Frequency_List[0]=(uint16_t)IST.min_frequency;
			Frequency_List[1]=2;
			Frequency_List[2]=5;
			Frequency_List[3]=10;
			Frequency_List[4]=25;
			Frequency_List[5]=50;
			Frequency_List[6]=75;
			Frequency_List[7]=100;
			Frequency_List[8]=150;
			Frequency_List[9]=200;
			Frequency_List[10]=250;
			Frequency_List[11]=300;Frequency_List[12]=400;Frequency_List[13]=500;Frequency_List[14]=600;Frequency_List[15]=750;Frequency_List[16]=1000;Frequency_List[17]=1500;Frequency_List[18]=2000;
			Frequency_List[19]=2500;Frequency_List[20]=3000;Frequency_List[21]=5000;Frequency_List[22]=6000;Frequency_List[23]=7500;Frequency_List[24]=9000;Frequency_List[25]=IST.max_frequency*1000;

			Frequency_List1[0]=IST.min_frequency;
			Frequency_List1[1]=2;
			Frequency_List1[2]=5;
			Frequency_List1[3]=10;
			Frequency_List1[4]=25;
			Frequency_List1[5]=50;
			Frequency_List1[6]=75;
			Frequency_List1[7]=100;
			Frequency_List1[8]=150;
			Frequency_List1[9]=200;
			Frequency_List1[10]=250;
			Frequency_List1[11]=300;Frequency_List1[12]=400;Frequency_List1[13]=500;Frequency_List1[14]=600;Frequency_List1[15]=750;Frequency_List1[16]=1000;Frequency_List1[17]=1500;Frequency_List1[18]=2000;
			Frequency_List1[19]=2500;Frequency_List1[20]=3000;Frequency_List1[21]=5000;Frequency_List1[22]=6000;Frequency_List1[23]=7500;Frequency_List1[24]=9000;Frequency_List1[25]=IST.max_frequency*1000;
		}

		else if(IST.min_frequency==10)
		{
			Frequency_List[0]=(uint16_t)IST.min_frequency;
			Frequency_List[1]=25;
			Frequency_List[2]=50;
			Frequency_List[3]=75;
			Frequency_List[4]=100;
			Frequency_List[5]=150;
			Frequency_List[6]=200;
			Frequency_List[7]=250;
			Frequency_List[8]=300;Frequency_List[9]=400;Frequency_List[10]=500;Frequency_List[11]=600;Frequency_List[12]=750;Frequency_List[13]=1000;Frequency_List[14]=1500;Frequency_List[15]=2000;
			Frequency_List[16]=2500;Frequency_List[17]=3000;Frequency_List[18]=5000;Frequency_List[19]=6000;Frequency_List[20]=7500;Frequency_List[21]=9000;Frequency_List[22]=(uint16_t)IST.max_frequency*1000;

			Frequency_List1[0]=IST.min_frequency;
			Frequency_List1[1]=25;
			Frequency_List1[2]=50;
			Frequency_List1[3]=75;
			Frequency_List1[4]=100;
			Frequency_List1[5]=150;
			Frequency_List1[6]=200;
			Frequency_List1[7]=250;
			Frequency_List1[8]=300;Frequency_List1[9]=400;Frequency_List1[10]=500;Frequency_List1[11]=600;Frequency_List1[12]=750;Frequency_List1[13]=1000;Frequency_List1[14]=1500;Frequency_List1[15]=2000;
			Frequency_List1[16]=2500;Frequency_List1[17]=3000;Frequency_List1[18]=5000;Frequency_List1[19]=6000;Frequency_List1[20]=7500;Frequency_List1[21]=9000;Frequency_List1[22]=IST.max_frequency*1000;
		}

		else if(IST.min_frequency==100)
				{
					Frequency_List[0]=(uint16_t)IST.min_frequency;
					Frequency_List[1]=150;
					Frequency_List[2]=200;
					Frequency_List[3]=250;
					Frequency_List[4]=300;Frequency_List[5]=400;Frequency_List[6]=500;Frequency_List[7]=600;Frequency_List[8]=750;Frequency_List[9]=1000;Frequency_List[10]=1500;Frequency_List[11]=2000;
					Frequency_List[12]=2500;Frequency_List[13]=3000;Frequency_List[14]=5000;Frequency_List[15]=6000;Frequency_List[16]=7500;Frequency_List[17]=9000;Frequency_List[18]=(uint16_t)IST.max_frequency*1000;

					Frequency_List1[0]=IST.min_frequency;
					Frequency_List1[1]=150;
					Frequency_List1[2]=200;
					Frequency_List1[3]=250;
					Frequency_List1[4]=300;Frequency_List1[5]=400;Frequency_List1[6]=500;Frequency_List1[7]=600;Frequency_List1[8]=750;Frequency_List1[9]=1000;Frequency_List1[10]=1500;Frequency_List1[11]=2000;
					Frequency_List1[12]=2500;Frequency_List1[13]=3000;Frequency_List1[14]=5000;Frequency_List1[15]=6000;Frequency_List1[16]=7500;Frequency_List1[17]=9000;Frequency_List1[18]=IST.max_frequency*1000;
				}
		else if(IST.min_frequency==1000)
				{
					Frequency_List[0]=(uint16_t)IST.min_frequency;Frequency_List[1]=1500;Frequency_List[2]=2000;
					Frequency_List[3]=2500;Frequency_List[4]=3000;Frequency_List[5]=5000;Frequency_List[6]=6000;Frequency_List[7]=7500;Frequency_List[8]=9000;Frequency_List[9]=(uint16_t)IST.max_frequency*1000;

					Frequency_List1[0]=IST.min_frequency;Frequency_List1[1]=1500;Frequency_List1[2]=2000;
					Frequency_List1[3]=2500;Frequency_List1[4]=3000;Frequency_List1[5]=5000;Frequency_List1[6]=6000;Frequency_List1[7]=7500;Frequency_List1[8]=9000;Frequency_List1[9]=IST.max_frequency*1000;
				}

		IS_Start();



	}
}
if(method==1)
{
	CV_Start();
	rand_count=2;

}
else if(method==2)
{
	SWV_Start();
	rand_count=2;

}
else if(method==4)
{
	DPV_Start();
	rand_count=2;

}
else if(method==3)
{
	IS_Complete();
	rand_count=2;
}
else
{
	rand_count=1;
}

    /* USER CODE END WHILE */

    /* USER CODE BEGIN 3 */
  }
  /* USER CODE END 3 */
}

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


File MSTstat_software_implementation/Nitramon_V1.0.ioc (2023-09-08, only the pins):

Mcu.UserName=STM32F303ZETx
PA13.Signal=SYS_JTMS-SWDIO
PA14.Signal=SYS_JTCK-SWCLK
PB3.Signal=SPI3_SCK
PB4.Signal=SPI3_MISO
PB5.Signal=SPI3_MOSI
PC10.Signal=UART4_TX
PC11.Signal=UART4_RX
PC12.Signal=UART5_TX
PD10.Signal=GPIO_Output
PD13.Signal=GPIO_Output
PD2.Signal=UART5_RX
PD8.Signal=GPIO_Output
PD9.Signal=GPIO_Output
PF0-OSC_IN.Signal=RCC_OSC_IN
PF1-OSC_OUT.Signal=RCC_OSC_OUT

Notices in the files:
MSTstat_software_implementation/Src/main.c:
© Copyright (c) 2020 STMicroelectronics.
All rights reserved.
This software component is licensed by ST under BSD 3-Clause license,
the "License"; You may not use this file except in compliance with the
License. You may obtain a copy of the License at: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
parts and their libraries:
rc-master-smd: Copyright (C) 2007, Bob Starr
